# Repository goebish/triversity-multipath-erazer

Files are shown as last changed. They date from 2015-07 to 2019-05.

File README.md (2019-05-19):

# DIY Triversity 5.8 Ghz Video Receiver







## Building

Requires Arduino >= 1.6

PDQ_GFX for ST7735 must be installed in the Arduino libraries folder.

## Usage

### Main dialog

Press left or right to change channel, long press enable auto scan

Press up to enter calibration / bargraph dialog

### Calibration procedure

Allow the Triversity receiver to warm up for at least 5-10 minutes before calibrating.

- Start with transmitter switched off
- Press left / right to manually set frequency to the same as your transmitter
- Press up to enter calibration / bargraph dialog
- Set gain potentiometers to their maximum position
- Adjust zero adjust potentiometers until every channel read the same value in the 50-60 range, lower is better, but they must read the same value, ie 51 51 51
- Switch transmitter on
- Adjust gain potentiometer until every channel read 1000
- Press up to exit calibration dialog

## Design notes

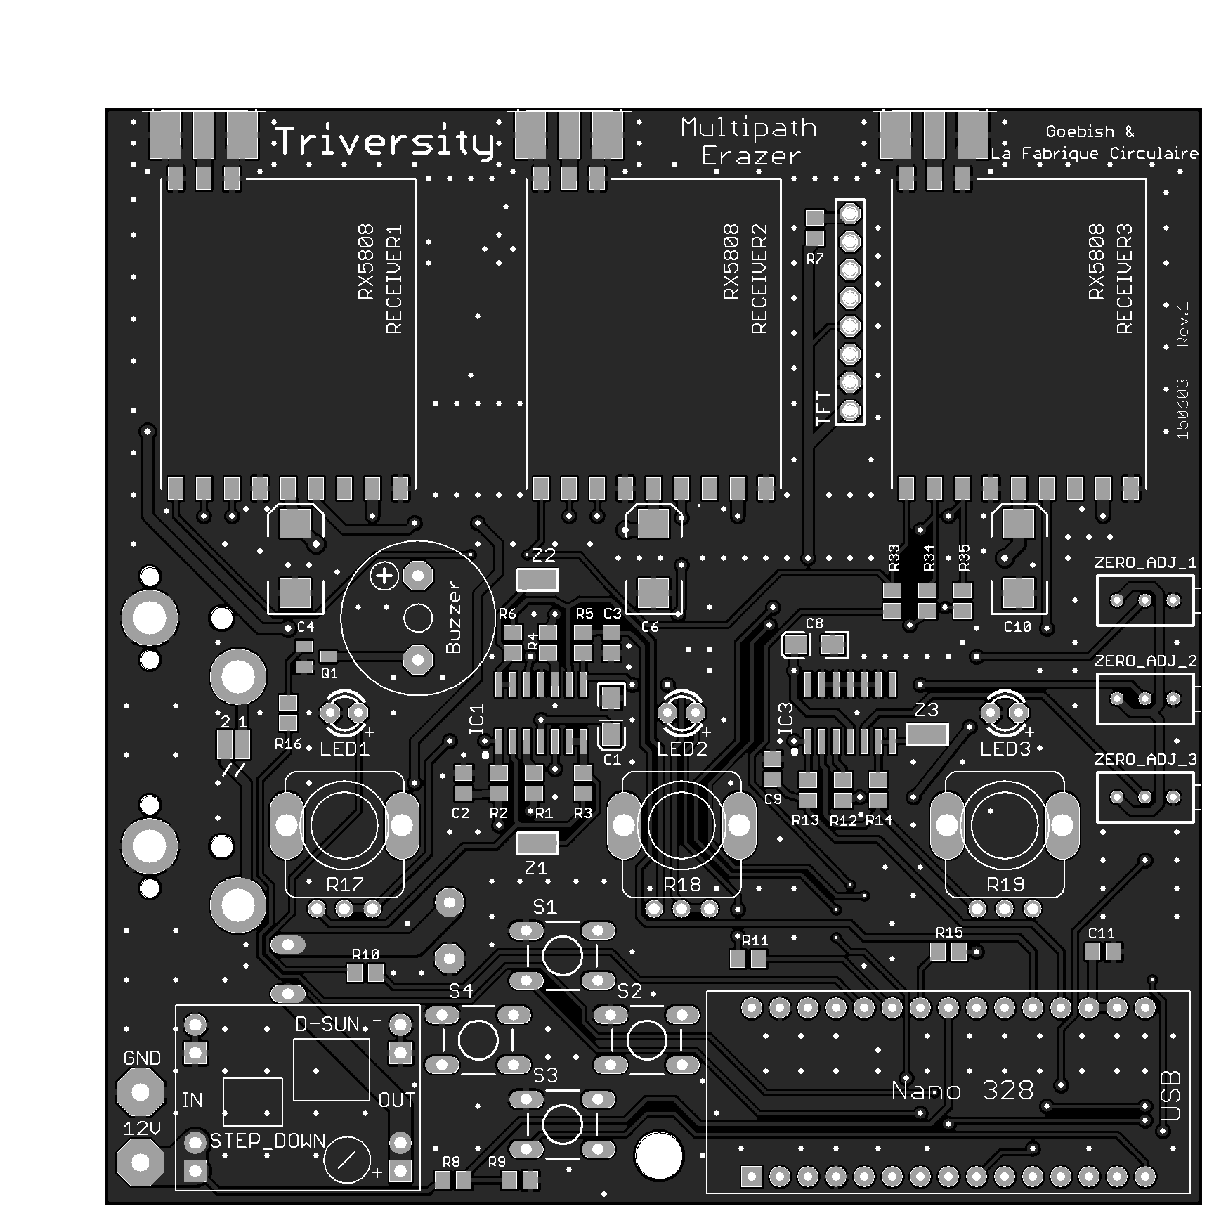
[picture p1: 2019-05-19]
Hardware/triversity_rev1_top.png

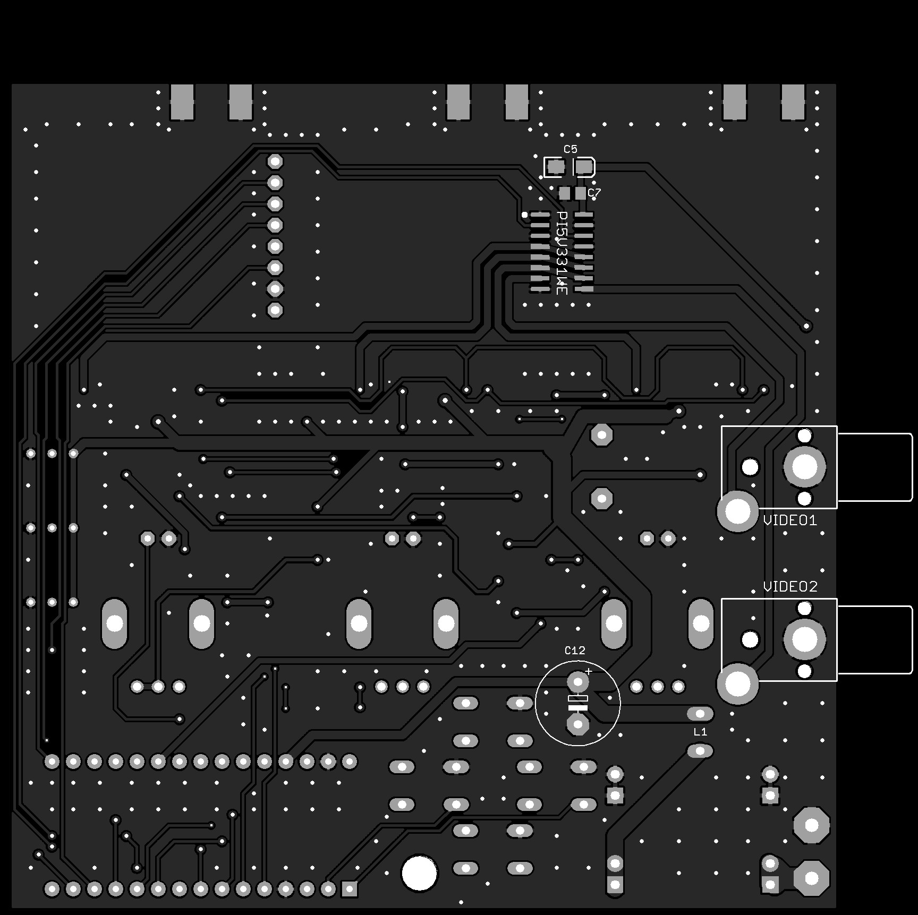
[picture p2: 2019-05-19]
Hardware/triversity_rev1_bottom.png

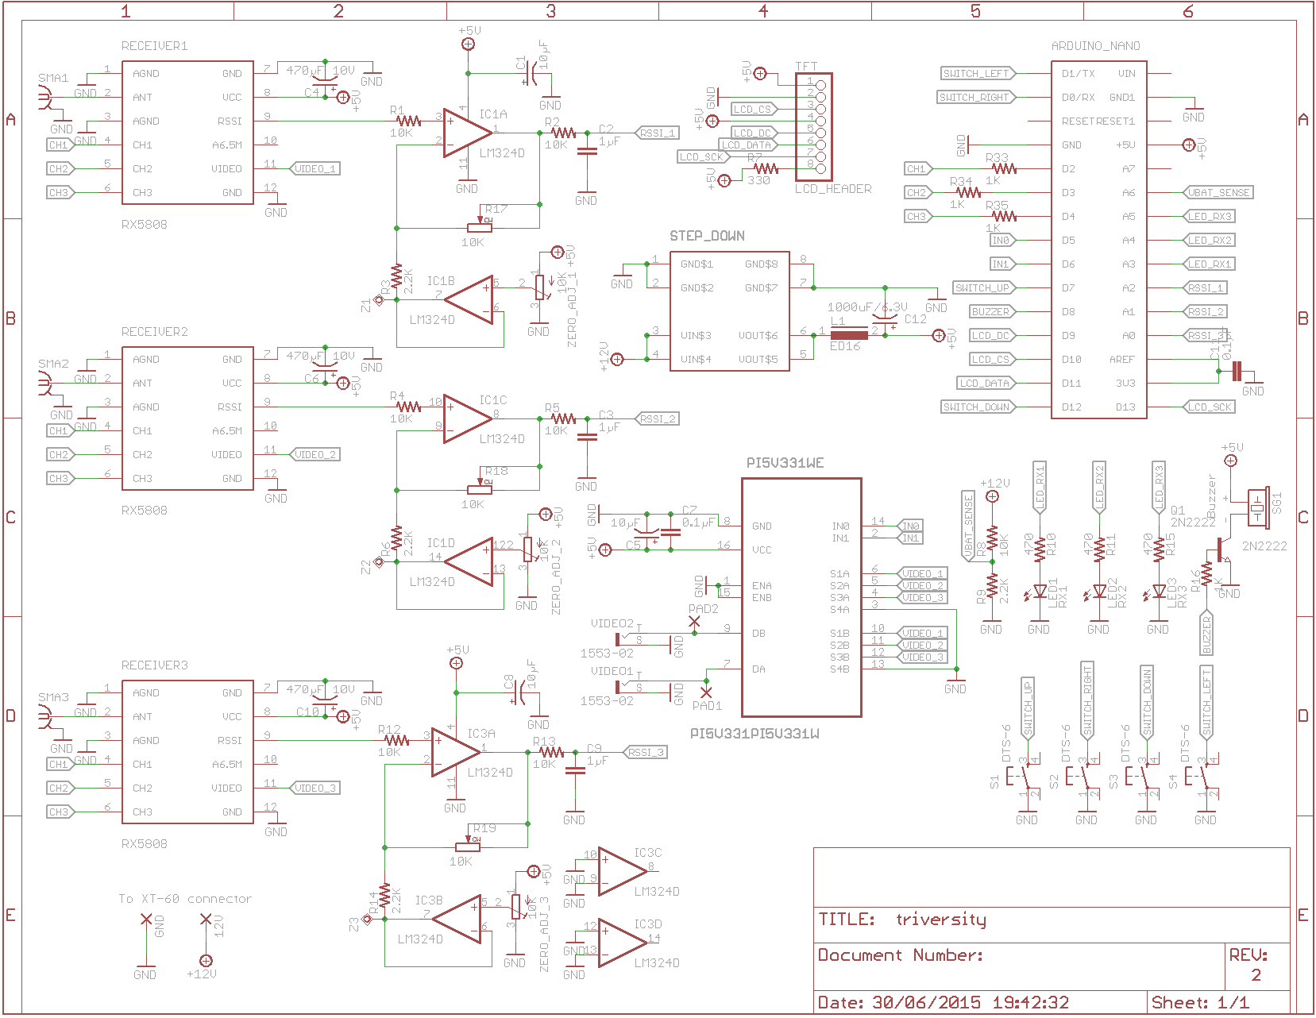
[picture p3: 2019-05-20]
Hardware/triversity_rev1.schematics.png

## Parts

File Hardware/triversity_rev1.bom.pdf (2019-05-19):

Parts | Qty | Value | Device
C7, C11 | 2 | 0.1µF | 0805 ceramic (2.0 mm × 1.25 mm)
C2, C3, C9 | 3 | 1µF | 0805 ceramic (2.0 mm × 1.25 mm)
R16, R33, R34, R35 | 4 | 1KΩ | 0805 (2.0 mm × 1.25 mm)
R3, R6, R9, R14 | 4 | 2.2K | 0805 (2.0 mm × 1.25 mm)
Q1 | 1 | 2N2222 | SOT23
C1, C5, C8 | 3 | 10µF | 1206 tantalum or ceramic (3.2 mm × 1.6 mm)
R17, R18, R19 | 3 | 10KΩ linear | Single RK09L
ZERO_ADJ_1, ZERO_ADJ_2, ZERO_ADJ_33 | 10KΩ | 3296X
R1, R2, R4, R5, R8, R12, R13 | 7 | 10KΩ | 0805 (2.0 mm × 1.25 mm)
R7 | 1 | 330Ω | 0805 (2.0 mm × 1.25 mm)
C4, C6, C10 | 3 | 470µF 10V | 7343 tantalum (7.3 mm × 4.3 mm)
R10, R11, R15 | 3 | 470Ω | 0805 (2.0 mm × 1.25 mm)
C12 | 1 | 1000uF 6.3V | PTH CPOL-USE5-10.5
VIDEO1, VIDEO2 | 2 | 1553-02 | RCA 1553-02
ARDUINO_NANO | 1 | ARDUINO NANO | Arduino Nano or clone
SG1 | 1 | Buzzer | F/CM12P
S1, S2, S3, S4 | 4 | DTS-6 | switch DTS-6 13mm
L1 | 1 | à déterminer … | ED16
TFT | 1 | ST7735 1.8" | 1.8" TFT LCD Display 128x160 Module ST7735S
IC1, IC3 | 2 | LM324D | SOIC-14
STEP_DOWN | 1 | BG SKU 951165 | Mini DC-DC Adjustable Power Supply Module
PI5V331WE | 1 | PI5V331WE | SOIC-16
LED1, LED2, LED3 | 3 | Ultra bright Red LED | PTH LED 3MM
RECEIVER1, RECEIVER2, RECEIVER3 | 3 | RX5808 | RX5808 SPI
SMA1, SMA2, SMA3 | 3 | SMA-142-0711-821/826 | SMA-142-0711-821/826

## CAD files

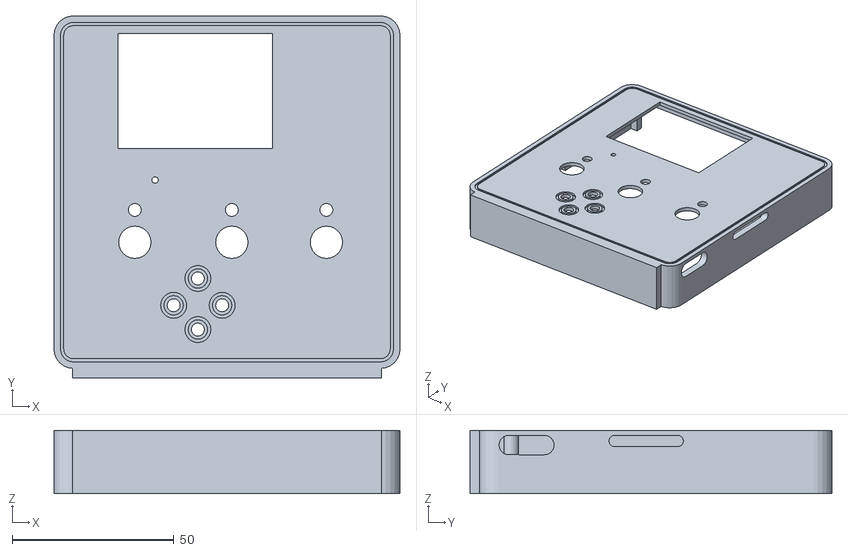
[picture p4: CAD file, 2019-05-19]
Hardware/casing/triversity_panel_front.stl
107.0 x 112.0 x 19.5

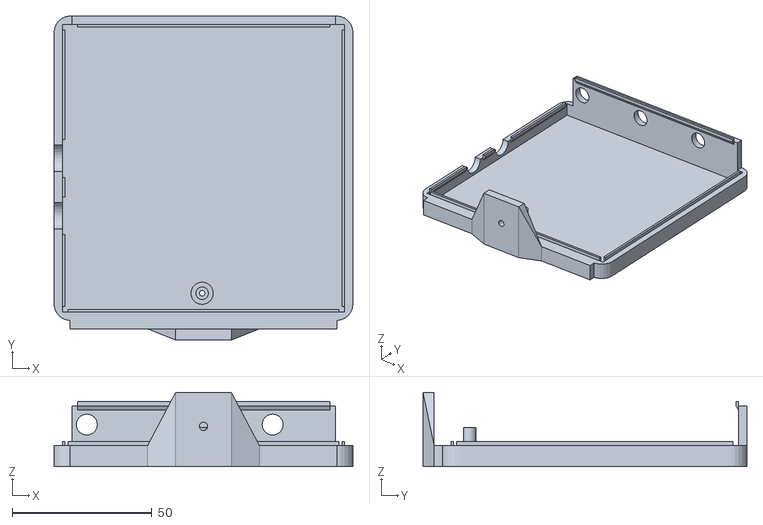
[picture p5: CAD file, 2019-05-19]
Hardware/casing/triversity_panel_back.stl
107.0 x 116.0 x 26.5

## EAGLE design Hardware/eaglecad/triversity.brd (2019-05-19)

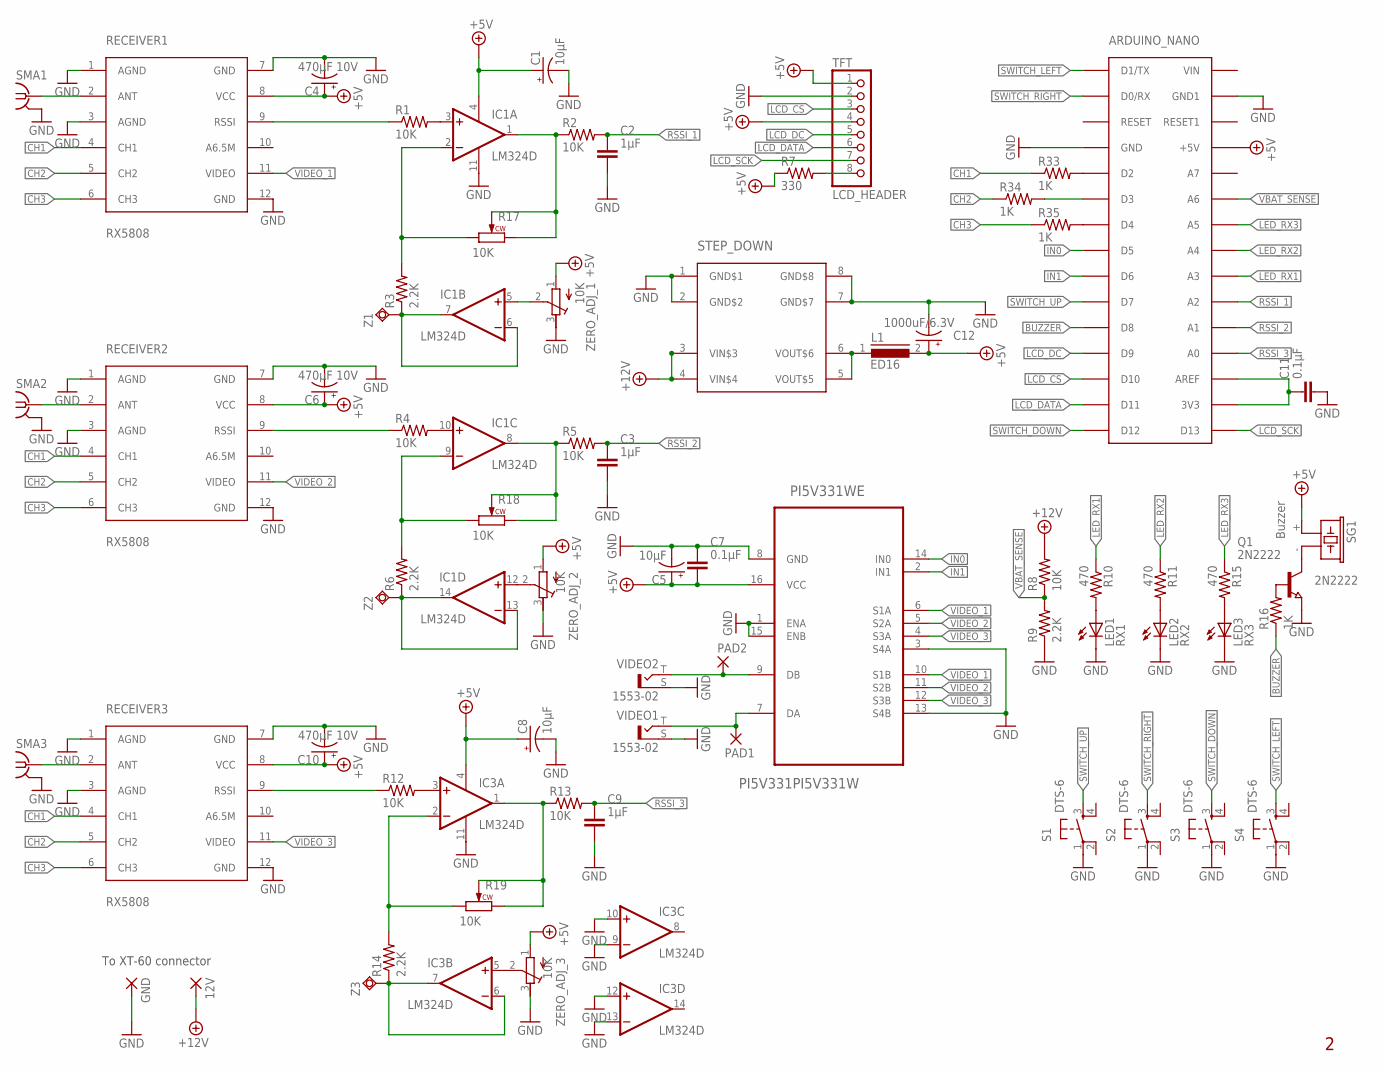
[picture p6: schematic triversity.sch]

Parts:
12V: WIREPAD4,16O1,6; 4,16O1,6
ARDUINO_NANO: ARDUINO_NANO; PDIP-32
C1, C5, C8: 10µF; EIA3216-KIT
C2, C3, C9: 1µF; C805
C4, C6, C10: 470µF 10V; EIA7343
C7, C11: 0.1µF; C805
C12: 1000uF/6.3V; E5-10,5
GND: WIREPAD4,16O1,6; 4,16O1,6
IC1, IC3: LM324D; SO14
L1: ED16
LED1: RX1; LED3MM
LED2: RX2; LED3MM
LED3: RX3; LED3MM
PAD1, PAD2: WIREPADSMD1,27-254; SMD1,27-2,54
PI5V331WE: PI5V331PI5V331W; SO16
Q1: 2N2222; SOT23
R1, R2, R4, R5, R8, R12, R13: 10K; M0805
R3, R6, R9, R14: 2.2K; M0805
R7: 330; M0805
R10, R11, R15: 470; M0805
R16, R33, R34, R35: 1K; M0805
R17, R18, R19: 10K; RK09L-SINGLE
RECEIVER1, RECEIVER2, RECEIVER3: RX5808
S1, S2, S3, S4: DTS-6
SG1: Buzzer; F/CM12P
SMA1, SMA2, SMA3: SMA-142-0711-821/826; J502-ND-142-0711-821/826
STEP_DOWN: LM2596_MODULE; LM2596-MODULE
TFT: LCD_HEADER; 1X08-CLEANBIG
VIDEO1, VIDEO2: 1553-02
Z1, Z2, Z3: TP-M; KEY-MINIATURE
ZERO_ADJ_1, ZERO_ADJ_2, ZERO_ADJ_3: 10K; RTRIM3296X

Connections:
3V3_AREF: ARDUINO_NANO.3V3, ARDUINO_NANO.AREF, C11.1
+5V: ARDUINO_NANO.+5V, C1.A (+), C4.A (+), C5.A (+), C6.A (+), C7.2, C8.A (+), C10.A (+), C12.+, IC1.4 (V+), IC3.4 (V+), L1.2, PI5V331WE.16 (VCC), R7.1, RECEIVER1.8 (VCC), RECEIVER2.8 (VCC), RECEIVER3.8 (VCC), SG1.+ (1), TFT.1, TFT.4, ZERO_ADJ_1.1 (E), ZERO_ADJ_2.1 (E), ZERO_ADJ_3.1 (E)
+12V: 12V.1, R8.2, STEP_DOWN.3 (VIN$3), STEP_DOWN.4 (VIN$4)
ANT1: RECEIVER1.2 (ANT), SMA1.1
ANT2: RECEIVER2.2 (ANT), SMA2.1
ANT3: RECEIVER3.2 (ANT), SMA3.1
BUZZER: ARDUINO_NANO.D8, R16.1
CH1: R33.1, RECEIVER1.4 (CH1), RECEIVER2.4 (CH1), RECEIVER3.4 (CH1)
CH2: R34.1, RECEIVER1.5 (CH2), RECEIVER2.5 (CH2), RECEIVER3.5 (CH2)
CH3: R35.1, RECEIVER1.6 (CH3), RECEIVER2.6 (CH3), RECEIVER3.6 (CH3)
GND: ARDUINO_NANO.GND, ARDUINO_NANO.GND1, C1.C (-), C2.2, C3.2, C4.C (-), C5.C (-), C6.C (-), C7.1, C8.C (-), C9.2, C10.C (-), C11.2, C12.-, GND.1, IC1.11 (V-), IC3.9 (-IN), IC3.10 (+IN), IC3.11 (V-), IC3.12 (+IN), IC3.13 (-IN), LED1.K (C), LED2.K (C), LED3.K (C), PI5V331WE.1 (ENA), PI5V331WE.3 (S4A), PI5V331WE.8 (GND), PI5V331WE.13 (S4B), PI5V331WE.15 (ENB), Q1.2 (E), R9.1, RECEIVER1.1 (AGND), RECEIVER1.3 (AGND), RECEIVER1.7 (GND), RECEIVER1.12 (GND), RECEIVER2.1 (AGND), RECEIVER2.3 (AGND), RECEIVER2.7 (GND), RECEIVER2.12 (GND), RECEIVER3.1 (AGND), RECEIVER3.3 (AGND), RECEIVER3.7 (GND), RECEIVER3.12 (GND), S1.1, S2.1, S3.1, S4.1, SMA1.G@1 (GND), SMA1.G@2 (GND), SMA1.G@3 (GND), SMA1.G@4 (GND), SMA2.G@1 (GND), SMA2.G@2 (GND), SMA2.G@3 (GND), SMA2.G@4 (GND), SMA3.G@1 (GND), SMA3.G@2 (GND), SMA3.G@3 (GND), SMA3.G@4 (GND), STEP_DOWN.1 (GND$1), STEP_DOWN.2 (GND$2), STEP_DOWN.7 (GND$7), STEP_DOWN.8 (GND$8), TFT.2, VIDEO1.S, VIDEO2.S, ZERO_ADJ_1.3 (A), ZERO_ADJ_2.3 (A), ZERO_ADJ_3.3 (A)
IN0: ARDUINO_NANO.D5, PI5V331WE.14 (IN0)
IN1: ARDUINO_NANO.D6, PI5V331WE.2 (IN1)
LCD_CS: ARDUINO_NANO.D10, TFT.3
LCD_DATA: ARDUINO_NANO.D11, TFT.6
LCD_DC: ARDUINO_NANO.D9, TFT.5
LCD_SCK: ARDUINO_NANO.D13, TFT.7
LED_RX1: ARDUINO_NANO.A3, R10.1
LED_RX2: ARDUINO_NANO.A4, R11.1
LED_RX3: ARDUINO_NANO.A5, R15.1
unnamed: IC1.3 (+IN), R1.2
unnamed: IC3.3 (+IN), R12.2
unnamed: IC1.1 (OUT), R2.1, R17.2 (W), R17.3 (CW)
unnamed: R7.2, TFT.8
unnamed: IC1.6 (-IN), IC1.7 (OUT), R3.1, Z1.P$1
unnamed: IC1.2 (-IN), R3.2, R17.1 (CCW)
unnamed: IC1.10 (+IN), R4.2
unnamed: IC1.5 (+IN), ZERO_ADJ_1.2 (S)
unnamed: IC1.8 (OUT), R5.1, R18.2 (W), R18.3 (CW)
unnamed: IC1.13 (-IN), IC1.14 (OUT), R6.1, Z2.P$1
unnamed: IC1.9 (-IN), R6.2, R18.1 (CCW)
unnamed: IC1.12 (+IN), ZERO_ADJ_2.2 (S)
unnamed: Q1.3 (C), SG1.- (2)
unnamed: IC3.1 (OUT), R13.1, R19.2 (W), R19.3 (CW)
unnamed: IC3.6 (-IN), IC3.7 (OUT), R14.1, Z3.P$1
unnamed: IC3.2 (-IN), R14.2, R19.1 (CCW)
unnamed: IC3.5 (+IN), ZERO_ADJ_3.2 (S)
unnamed: LED1.A, R10.2
unnamed: Q1.1 (B), R16.2
unnamed: L1.1, STEP_DOWN.5 (VOUT$5), STEP_DOWN.6 (VOUT$6)
unnamed: LED2.A, R11.2
unnamed: LED3.A, R15.2
unnamed: ARDUINO_NANO.D2, R33.2
unnamed: ARDUINO_NANO.D3, R34.2
unnamed: ARDUINO_NANO.D4, R35.2
RAW_RSSI1: R1.1, RECEIVER1.9 (RSSI)
RAW_RSSI2: R4.1, RECEIVER2.9 (RSSI)
RAW_RSSI3: R12.1, RECEIVER3.9 (RSSI)
RSSI_1: ARDUINO_NANO.A2, C2.1, R2.2
RSSI_2: ARDUINO_NANO.A1, C3.1, R5.2
RSSI_3: ARDUINO_NANO.A0, C9.1, R13.2
SWITCH_DOWN: ARDUINO_NANO.D12, S3.3
SWITCH_LEFT: ARDUINO_NANO.D1/TX, S4.3
SWITCH_RIGHT: ARDUINO_NANO.D0/RX, S2.3
SWITCH_UP: ARDUINO_NANO.D7, S1.3
VBAT_SENSE: ARDUINO_NANO.A6, R8.1, R9.2
VIDEO_1: PI5V331WE.6 (S1A), PI5V331WE.10 (S1B), RECEIVER1.11 (VIDEO)
VIDEO_2: PI5V331WE.5 (S2A), PI5V331WE.11 (S2B), RECEIVER2.11 (VIDEO)
VIDEO_3: PI5V331WE.4 (S3A), PI5V331WE.12 (S3B), RECEIVER3.11 (VIDEO)
VIDEO_OUT1: PAD1.1, PI5V331WE.7 (DA), VIDEO1.T
VIDEO_OUT2: PAD2.1, PI5V331WE.9 (DB), VIDEO2.T

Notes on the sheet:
To XT-60 connector
2N2222

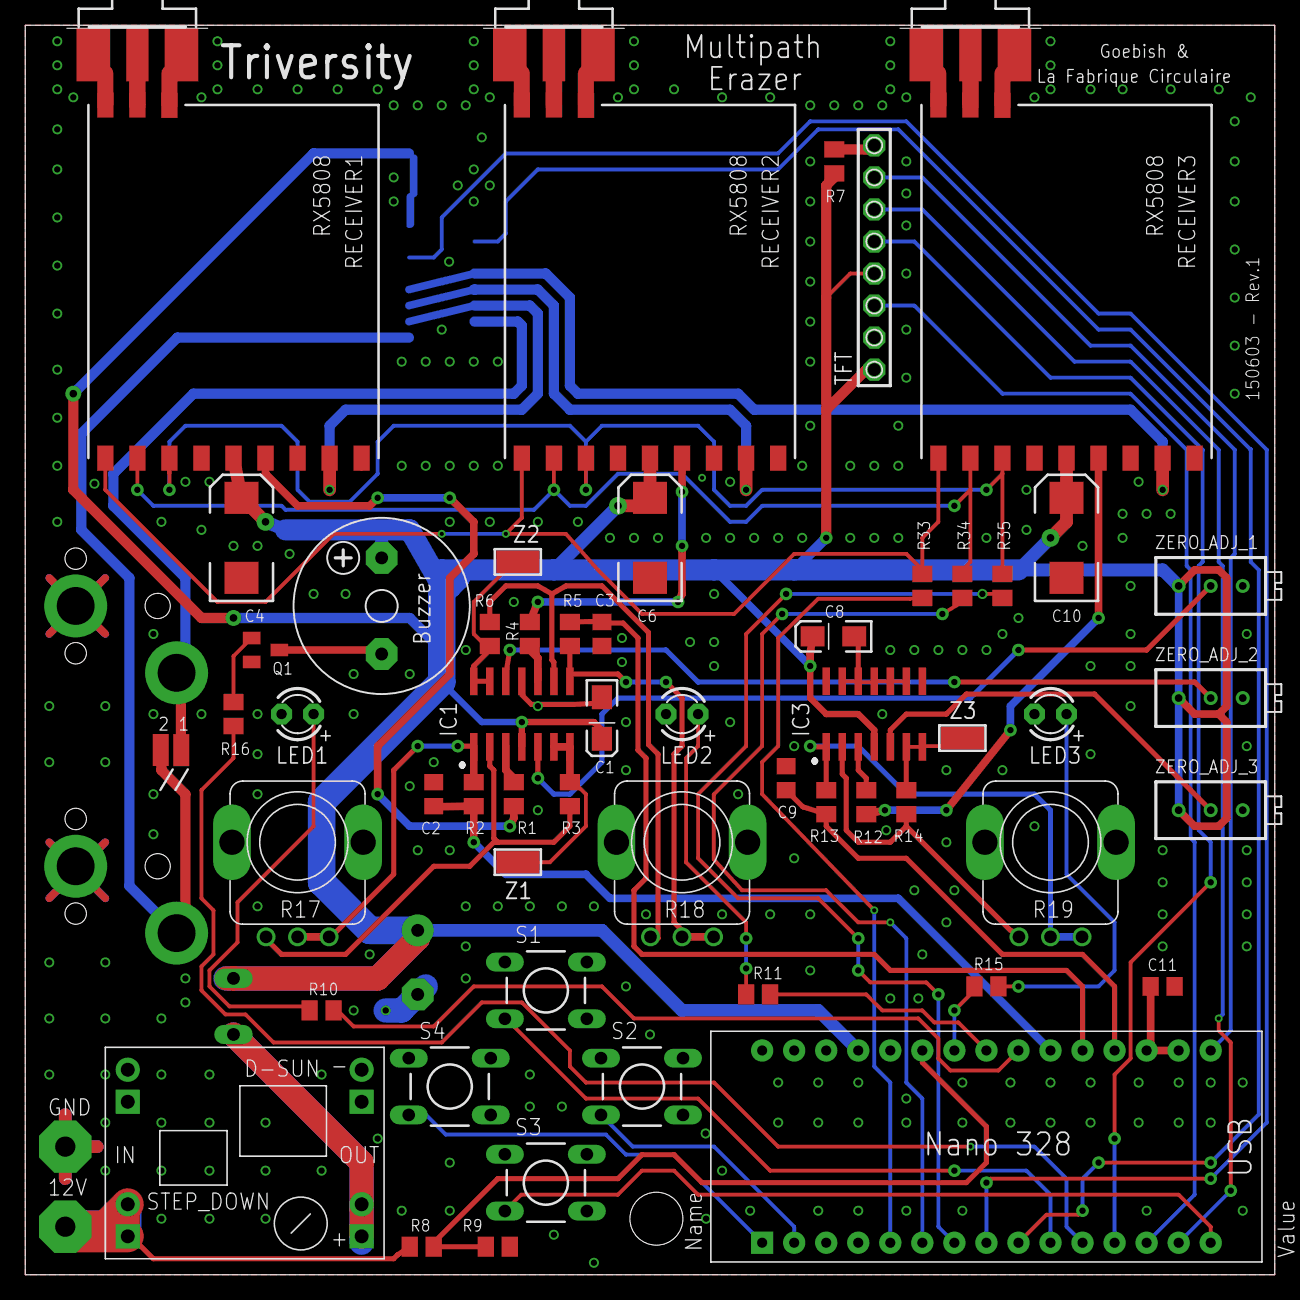
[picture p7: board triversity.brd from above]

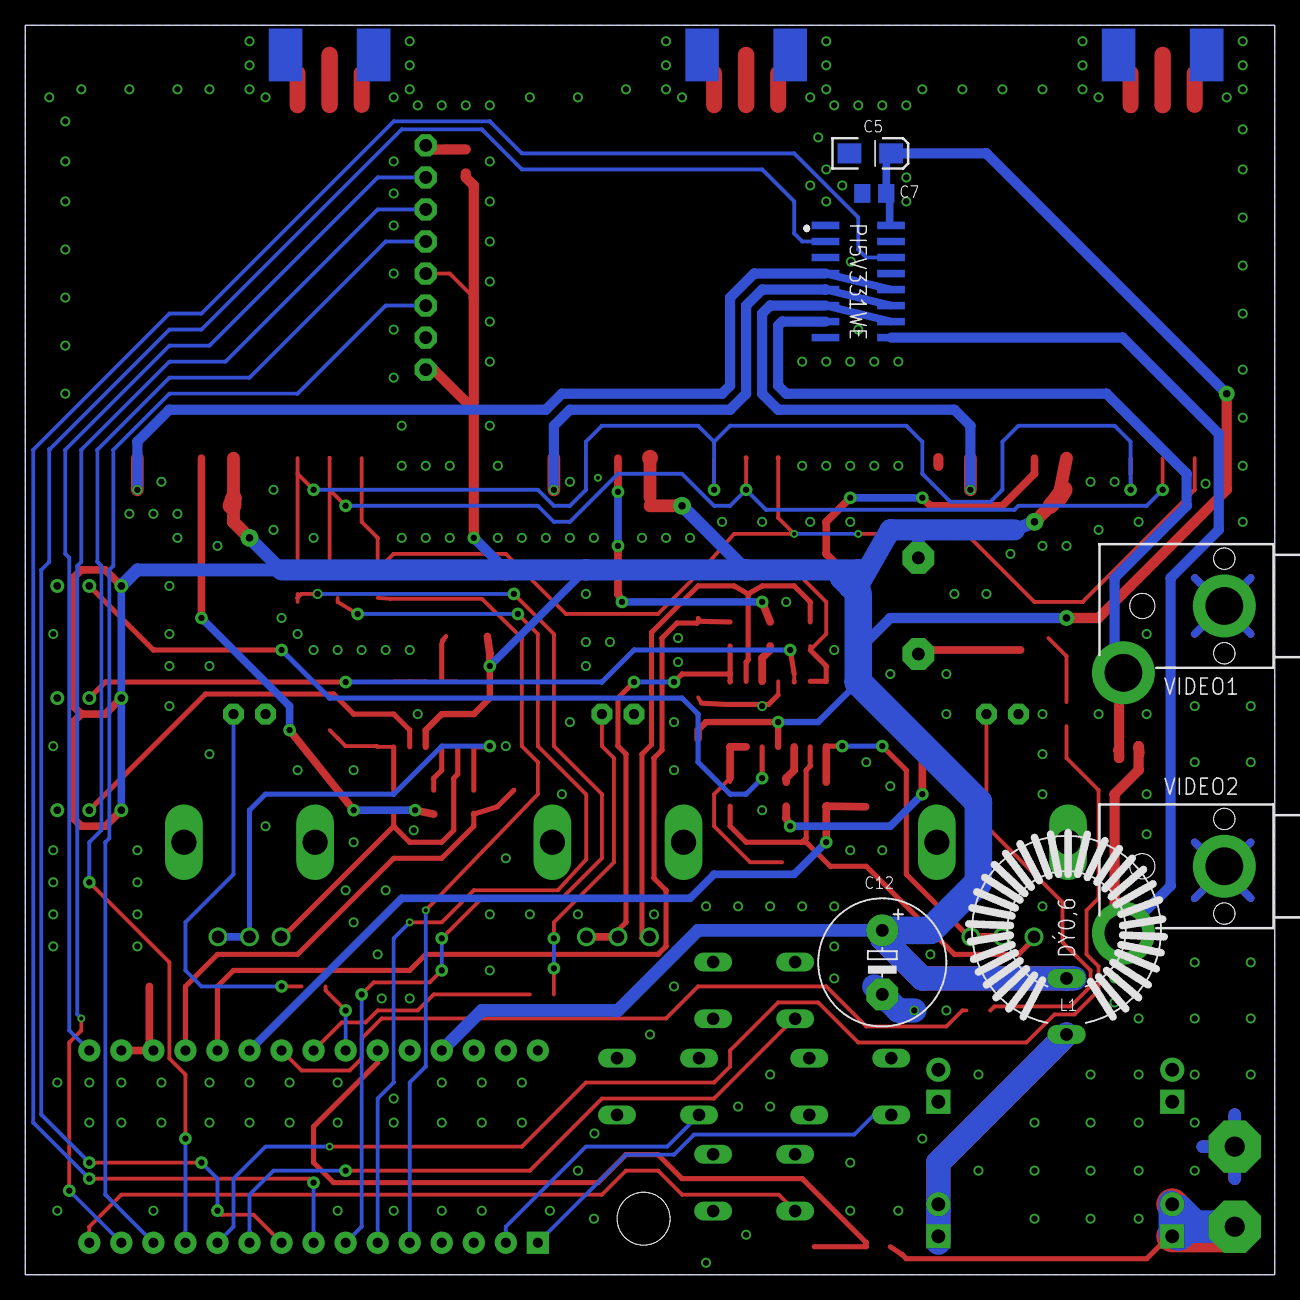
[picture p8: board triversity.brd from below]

Board: 2 copper layers, 99.1 x 99.1 mm, 69 parts (7 on the bottom side), 61 nets.

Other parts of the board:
U$1: ST7735-SPI

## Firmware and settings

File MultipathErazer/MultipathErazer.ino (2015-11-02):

#include "config.h"
#include "utils.h"
#include "pinout.h"
#include "display.h"
#include <PDQ_GFX.h>
#include "PDQ_ST7735_config.h"
#include <PDQ_ST7735.h>
PDQ_ST7735 tft;

#define NUMBER_OF_RECEIVER 3
#define VBAT_FACTOR 190
#define RSSI_STABILIZATION_TIME 50

const unsigned char RSSI_Pin[3] = { A2, A1, A0}; //Analog Pin

// Channels with their Mhz Values
const uint16_t channelFreqTable[] PROGMEM = {
    // Channel 1 - 8
    5865, 5845, 5825, 5805, 5785, 5765, 5745, 5725, // Band A  00 - 07
    5733, 5752, 5771, 5790, 5809, 5828, 5847, 5866, // Band B  08 - 15
    5705, 5685, 5665, 5645, 5885, 5905, 5925, 5945, // Band E  16 - 23
    5740, 5760, 5780, 5800, 5820, 5840, 5860, 5880, // IRC/FS  24 - 31
    5658, 5695, 5732, 5769, 5806, 5843, 5880, 5917  // Race    32 - 39
};

// All Channels of the above list ordered by Mhz
const uint8_t channelList[] PROGMEM = {
    19, 32, 18, 17, 33, 16,  7, 34,  8, 24,
     6,  9, 25,  5, 35, 10, 26,  4, 11, 27,
     3, 36, 12, 28,  2, 13, 29, 37,  1, 14,
    30,  0, 15, 31, 38, 20, 21, 39, 22, 23
};

const uint8_t beep_length[4] = {0, 1, 4, 10};

uint16_t RSSI_Value[NUMBER_OF_RECEIVER];
uint8_t vbat;
uint8_t MaxSource = 0;
int16_t max_rssi = 0;
int8_t max_rssi_scan_index;
bool show_active_leds = true;
uint8_t current_menu_item;
boolean scan_first_pass = true;
uint16_t scan_max_found = 0;
uint16_t scan_last_max_found = 0;
uint8_t scan_channel;
uint8_t channelIndex;
uint8_t scan_best_index=0;
uint16_t anim_count;
uint32_t last_switch_beep=0;
bool searching=false;

// timers
uint32_t saveSettings = 0;
uint32_t checkVbat = 0;

enum e_STATES{
    STATE_MAIN,      // channel selection
    STATE_MAIN_MENU, // main menu
    STATE_CALIB,     // bar graph
    STATE_SCANNER,   // band scanner
    STATE_SETTINGS_MENU,  // settings menu
};

static uint8_t state = STATE_MAIN;

void setup()
{
    // read settings from eeprom
    readConfig();
    // init vRXs
    SPI_vRX_init();
    // init display
    TFT_init_display();
    // set analog reference
    analogReference(EXTERNAL);
    // setup leds
    DDRC |= 0b00111000; // output
    // setup pi5v331
    initSwitcher();
    // setup switches
    DDRD &= ~0b10000011; // input
    DDRB &= ~0b00010000;
    PORTD|=  0b10000011; // pull up
    PORTB|=  0b00010000;
    // setup buzzer
    DDRB |= 0b00000001; // output
    BUZZ_OFF;
    // setup 250khz adc (slightly more than recommended 200 khz max setting
    //setAdcPrescaler(ADC_PS_64);

    // splash screen
    displaySplash();

    // start with main dialog
    initState();
}

void loop()
{
    switch(state) {
        case STATE_MAIN:
            processMainState();
            break;
        case STATE_CALIB:
            processCalibState();
            break;
        case STATE_MAIN_MENU:
            processMainMenu();
            break;
        case STATE_SCANNER:
            processScanner();
            break;
        case STATE_SETTINGS_MENU:
            processSettingsMenu();
            break;
    }

    // save settings to eeprom
    if(saveSettings && millis() > saveSettings)
    {
        writeConfig();
        saveSettings = 0;
    }

    // refresh vbat
    if(millis() > checkVbat) {
        checkVbat = millis() + 20000; // check every 20s
        vbat = map( analogRead(VBAT)*10, 0, 10240, 0, VBAT_FACTOR);
        updateMainDialog(_BV(MAIN_BATTERY));
    }

    alarmBeep();
    switchBestRSSI();
}

void initState()
{
    switch(state) {
        case STATE_MAIN:
            updateMainDialog(_BV(MAIN_INIT) | _BV(MAIN_BAND) | _BV(MAIN_CHANNEL));
            SPI_vRX_set_frequency(pgm_read_word_near(channelFreqTable + config.current_channel));
            show_active_leds=true;
            break;
        case STATE_CALIB:
            updateCalibDialog(_BV(CALIB_INIT) | _BV(CALIB_HEADER));
            show_active_leds=true;
            break;
        case STATE_MAIN_MENU:
            current_menu_item = MAIN_MENU_EXIT;
            updateMainMenuDialog(_BV(MAIN_MENU_INIT) | _BV(MAIN_MENU_ITEMS));
            show_active_leds=true;
            break;
        case STATE_SCANNER:
            scan_first_pass = true;
            scan_max_found = 0;
            scan_last_max_found = 0;
            searching = true;
            updateScannerDialog(_BV(SCANNER_INIT));
            show_active_leds=false;
            scan_channel = 0;
            channelIndex = pgm_read_byte_near(channelList + scan_channel);
            SPI_vRX_set_frequency(pgm_read_word_near(channelFreqTable + channelIndex));
            delay(100);
            break;
        case STATE_SETTINGS_MENU:
            current_menu_item = SETTINGS_MENU_EXIT;
            updateSettingsMenuDialog(_BV(SETTINGS_MENU_INIT) | _BV(SETTINGS_MENU_ITEMS));
            show_active_leds=true;
            break;
    }
}

void processSettingsMenu()
{
    uint8_t i;
    if(BTN_UP || BTN_DOWN) {
        if(BTN_UP && current_menu_item > 0) {
            shortbeep();
            current_menu_item --;
            updateSettingsMenuDialog(_BV(SETTINGS_MENU_ITEMS));
        } else
        if(BTN_DOWN && current_menu_item < SETTINGS_MENU_NB_ITEMS-1) {
            shortbeep();
            current_menu_item ++;
            updateSettingsMenuDialog(_BV(SETTINGS_MENU_ITEMS));
        }
        waitButtonsRelease();
    } else
    if(BTN_LEFT || BTN_RIGHT) {
        shortbeep();
        uint8_t auto_repeat = 4;
        switch(current_menu_item) {
            case SETTINGS_MENU_EXIT:
                state = STATE_MAIN_MENU;
                initState();
                saveSettings = millis();
                waitButtonsRelease();
                break;
            case SETTINGS_MENU_VBAT_ALARM:
                if(BTN_LEFT && config.vbat_alarm > VBAT_ALARM_MIN)
                        config.vbat_alarm --;
                else if(BTN_RIGHT && config.vbat_alarm < VBAT_ALARM_MAX)
                        config.vbat_alarm ++;
                vbat = map( analogRead(VBAT)*10, 0, 10240, 0, VBAT_FACTOR);
                updateMainDialog(_BV(MAIN_BATTERY) | _BV(MAIN_FORCE_BATTERY_REDRAW));
                updateSettingsMenuDialog(_BV(SETTINGS_MENU_CHANGE_SETTING));
                while(BTN_ANY && auto_repeat--)
                    delay(50);
                break;
            case SETTINGS_MENU_BEEP_VOLUME:
                if(BTN_LEFT && config.beep_volume > BEEP_OFF)
                    config.beep_volume--;
                else if(BTN_RIGHT && config.beep_volume < BEEP_LOUDER)
                    config.beep_volume++;
                updateSettingsMenuDialog(_BV(SETTINGS_MENU_CHANGE_SETTING));
                waitButtonsRelease();
                break;
            case SETTINGS_MENU_PERIOD:
                if(BTN_LEFT && config.switch_period > 0)
                    if(config.switch_period <= 50)
                        config.switch_period--;
                    else
                        config.switch_period -= 10;
                else if(BTN_RIGHT && config.switch_period < MAX_PERIOD)
                    if(config.switch_period < 50)
                        config.switch_period++;
                    else
                        config.switch_period += 10;
                updateSettingsMenuDialog(_BV(SETTINGS_MENU_CHANGE_SETTING));
                while(BTN_ANY && auto_repeat--)
                    delay(15);
                break;
            case SETTINGS_MENU_FACTORY_RESET:
                for(i=0; i<3; i++) {
                    BUZZ_ON;
                    delay(100);
                    BUZZ_OFF;
                    delay(100);
                }
                state = STATE_MAIN;
                resetConfig();
                initState();
                waitButtonsRelease();
                break;
        }
    }
}

void processScanner()
{
    if(BTN_ANY) {
        if(scan_first_pass) {
            searching = false;
            shortbeep();
            state = STATE_MAIN;
            initState();
            waitButtonsRelease();
            return;
        }
        if(searching) {
            shortbeep();
            show_active_leds = true;
            searching = false;
            updateScannerDialog(_BV(SCANNER_CHOICE));
            SPI_vRX_set_frequency(pgm_read_word_near(channelFreqTable + scan_best_index));
            waitButtonsRelease();
            return;
        }
        if(BTN_LEFT) { // No
            shortbeep();
            state = STATE_MAIN;
            initState();
            waitButtonsRelease();
            return;
        } else
        if(BTN_RIGHT) { // Yes
            shortbeep();
            config.current_channel = scan_best_index;
            saveSettings = millis();
            state = STATE_MAIN;
            initState();
            waitButtonsRelease();
            return;
        }
    }
    if(searching) {
        channelIndex = pgm_read_byte_near(channelList + scan_channel);
        PORTC = (PORTC & ~0b111000) | (0b1000 << ((anim_count++/2) % NUMBER_OF_RECEIVER));
        SPI_vRX_set_frequency(pgm_read_word_near(channelFreqTable + channelIndex));
        updateScannerDialog(_BV(SCANNER_MARKER));
        wait(RSSI_STABILIZATION_TIME);
        switchBestRSSI();
        updateScannerDialog(_BV(SCANNER_GRAPH));
        if(max_rssi > scan_max_found) {
            scan_max_found = max_rssi;
            max_rssi_scan_index = scan_channel;
            if(scan_max_found > scan_last_max_found && !scan_first_pass) {
                updateScannerDialog(_BV(SCANNER_BEST));
                scan_best_index = pgm_read_byte_near(channelList + max_rssi_scan_index);
                scan_last_max_found = scan_max_found;
            }
        }
        scan_channel ++;
        if(scan_channel > 39) {
            scan_first_pass = false;
            updateScannerDialog(_BV(SCANNER_BEST));
            scan_best_index = pgm_read_byte_near(channelList + max_rssi_scan_index);
            scan_channel = 0;
            scan_last_max_found = scan_max_found;
            scan_max_found = 0;
        }
    }        
}

void processCalibState()
{
    static uint32_t refresh;
    if(BTN_RIGHT || BTN_LEFT) { // change current channel
        changeChannel();
    } else
    if(BTN_DOWN || BTN_UP) // return to main dialog
    {
        shortbeep();
        state = STATE_MAIN;
        initState();
        waitButtonsRelease();
        return;
    }
    if(millis() > refresh) {
        refresh = millis() + 1000/5; // x fps
        updateCalibDialog(_BV(CALIB_VALUES) | _BV(CALIB_BARS));
    }
}

void processMainMenu()
{
    if(BTN_UP || BTN_DOWN) {
        if(BTN_UP && current_menu_item > 0) {
            shortbeep();
            current_menu_item --;
            updateMainMenuDialog(_BV(MAIN_MENU_ITEMS));
        } else
        if(BTN_DOWN && current_menu_item < MAIN_MENU_NB_ITEMS-1) {
            shortbeep();
            current_menu_item ++;
            updateMainMenuDialog(_BV(MAIN_MENU_ITEMS));
        }
        waitButtonsRelease();
    } else
    if(BTN_LEFT || BTN_RIGHT) {
        shortbeep();
        switch(current_menu_item) {
            case MAIN_MENU_EXIT:
                state = STATE_MAIN;
                break;
            case MAIN_MENU_LEVELS:
                state = STATE_CALIB;
                break;
            case MAIN_MENU_SCANNER:
                state = STATE_SCANNER;
                break;
            case MAIN_MENU_SETTINGS:
                state = STATE_SETTINGS_MENU;
                break;
        }
        waitButtonsRelease();
        initState();
    }
}

// previous / next channel, long press = auto search
void changeChannel()
{
        shortbeep();
        if(BTN_RIGHT) {
            config.current_channel ++;
            if(config.current_channel > 39) {
                config.current_channel = 0;
            }
        }
        else if(BTN_LEFT) {
            config.current_channel --;
            if(config.current_channel < 0) {
                config.current_channel = 39;
            }
        }
        SPI_vRX_set_frequency(pgm_read_word_near(channelFreqTable + config.current_channel));
        switch(state) {
            case STATE_MAIN:
                updateMainDialog(_BV(MAIN_BAND) | _BV(MAIN_CHANNEL));
                break;
            case STATE_CALIB:
                updateCalibDialog(_BV(CALIB_HEADER));
                break;
        }
        uint8_t autoRepeat = 4;
        while(BTN_ANY && autoRepeat--) {
            delay(40);
            switchBestRSSI();
        }
        // long press = auto scan
        if(BTN_ANY && max_rssi < config.auto_threshold) {
            searching = true;
            tft.setTextColor(ST7735_WHITE, ST7735_BLACK);
            tft.setTextSize(1);
            switch(state) {
                case STATE_MAIN:
                    tft.setCursor(5,4);
                    break;
                case STATE_CALIB:
                    updateCalibDialog( _BV(CALIB_RESET_BARS) | _BV(CALIB_BARS));
                    tft.fillRect(36, 39, 84 , 16, ST7735_BLACK);
                    tft.drawRect(36, 39, 84 , 16, ST7735_WHITE);
                    tft.setCursor(40, 43);
                    break;
            }
            printText(&misc_string[STRING_SEARCHING]);
            int8_t direction=1;
            if(BTN_LEFT) {
                direction = -1;
            }
            bool button_released=false;
            show_active_leds=false;
            while(!BTN_ANY || !button_released) {
                config.current_channel += direction;
                if(config.current_channel > 39) {
                    config.current_channel = 0;
                }
                if(config.current_channel < 0) {
                    config.current_channel = 39;
                }
                SPI_vRX_set_frequency(pgm_read_word_near(channelFreqTable + config.current_channel));
                // LEDs animation
                anim_count += direction;
                PORTC = (PORTC & ~0b111000) | (0b1000 << ((anim_count/2) % NUMBER_OF_RECEIVER));
                switch(state) {
                    case STATE_MAIN:
                        updateMainDialog(_BV(MAIN_BAND) | _BV(MAIN_CHANNEL));
                        break;
                    case STATE_CALIB:
                        updateCalibDialog(_BV(CALIB_HEADER));
                        break;
                }
                // let rx stabilize on new frequency
                if((direction == 1 && config.current_channel % 8 == 0) ||
                   (direction ==-1 && config.current_channel % 8 == 7)) {
                    shortbeep(); // beep on band change
                    wait(RSSI_STABILIZATION_TIME-8);
                } else {
                    wait(RSSI_STABILIZATION_TIME);
                }
                switchBestRSSI();
                if(state == STATE_CALIB) {
                    updateCalibDialog(_BV(CALIB_BARS) | _BV(CALIB_VALUES));
                }
                // signal found ?
                if(max_rssi >= config.auto_threshold) {
                    // try to avoid false positive
                    wait(RSSI_STABILIZATION_TIME*3);
                    switchBestRSSI();
                    if(max_rssi >= config.auto_threshold) {
                        shortbeep();
                        delay(100);
                        shortbeep();
                        delay(100);
                        break;
                    }                        
                }
                if(!BTN_ANY) {
                    button_released = true;
                }
                alarmBeep();
            }
            if(state == STATE_MAIN) {
                refreshTitle();
            }
            else if(state == STATE_CALIB) {
                tft.fillRect(36, 39, 84 , 16, ST7735_BLACK);
                updateCalibDialog(_BV(CALIB_SCALES));
            }
            shortbeep();
        }
        searching = false;
        waitButtonsRelease();
        saveSettings = millis() + 3000; // save settings 3s after last change
        show_active_leds = true;
}

void processMainState()
{
    if(BTN_UP || BTN_DOWN) { // main menu
        shortbeep();
        state = STATE_MAIN_MENU; // STATE_CALIB;
        initState();
        waitButtonsRelease();
        return;
    } else
    if(BTN_RIGHT || BTN_LEFT) { // change current channel
        changeChannel();
    }
}

void switchBestRSSI()
{
    static uint32_t next_switch = 0;
    max_rssi = 0;
    for(uint8_t i = 0; i < NUMBER_OF_RECEIVER; i++) {
        RSSI_Value[i] = analogRead(RSSI_Pin[i]);
        if(RSSI_Value[i] > max_rssi) {
            max_rssi = RSSI_Value[i];
            MaxSource = i;
        }
    }
    if(millis() >= next_switch) {
        select(MaxSource);
        next_switch = millis() + config.switch_period;
    }
}

// short blocking beep for button press
void shortbeep()
{
    BUZZ_ON;
    delay(8);
    BUZZ_OFF;
}

// alarm beep management, must be called regularly
void alarmBeep()
{
    if(vbat <= config.vbat_alarm) {
        // every 5 seconds
        uint32_t now = millis() % 5000;
        // for 2 seconds
        if(now < 2000) {
            // beep 250ms every 500ms
            if(now%500 < 250) {
                BUZZ_ON;
            } else {
                BUZZ_OFF;
            }
        }
    }
    else if(searching==false && millis() < last_switch_beep + beep_length[config.beep_volume]) {
        BUZZ_ON;
    } else
        BUZZ_OFF;
}

// wait buttons release
void waitButtonsRelease()
{
    uint32_t timeout;
    while(BTN_ANY) {
        timeout = millis()+20;
        while(millis() < timeout)
            switchBestRSSI();
        alarmBeep();
    }
}

// wait or exit if button press
void wait(uint8_t msec)
{
    uint32_t timeout = millis() + msec;
    while(!BTN_ANY && millis() < timeout) {
        ;
    }
}

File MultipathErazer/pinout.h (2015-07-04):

// global pinout

// TFT LCD
#define TFT_CS (uint8_t)    10
#define TFT_RST (uint8_t)   A7   // connected to +3.3
#define TFT_DC (uint8_t)    9
#define TFT_SCLK (uint8_t)  13
#define TFT_DATA (uint8_t)  11

// buttons
#define BTN_UP_PIN  (uint8_t)   7
#define BTN_RIGHT_PIN (uint8_t) 0
#define BTN_DOWN_PIN (uint8_t)  12
#define BTN_LEFT_PIN (uint8_t)  1

#define BTN_UP      (!(PIND & 0b10000000))
#define BTN_RIGHT   (!(PIND & 0b00000001))
#define BTN_DOWN    (!(PINB & 0b00010000))
#define BTN_LEFT    (!(PIND & 0b00000010))
#define BTN_ANY     (BTN_UP|BTN_RIGHT|BTN_LEFT|BTN_DOWN)


// SPI vRX
#define VRX_DATA (uint8_t)  2 // PD2 - CH1 
#define VRX_EN (uint8_t)    3 // PD3 - CH2
#define VRX_CLK (uint8_t)   4 // PD4 - CH3

// RSSI vRX
#define RSSI_1 (uint8_t)    A2
#define RSSI_2 (uint8_t)    A1
#define RSSI_3 (uint8_t)    A0 

// LEDs
#define LED_VRX_1 (uint8_t) A3 
#define LED_VRX_2 (uint8_t) A4 
#define LED_VRX_3 (uint8_t) A5 

// analog multiplexer control
#define PI5V311_IN0 (uint8_t) 5 // PD5
#define PI5V311_IN1 (uint8_t) 6 // PD6

// misc
#define BUZZER (uint8_t)    8   // PB0
#define BUZZ_OFF PORTB &= ~0b00000001
#define BUZZ_ON  PORTB |=  0b00000001

#define VBAT (uint8_t)      A6

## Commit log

2015-07-04 Show led for active vRX + all other vRX(s) with same RSSI
2015-07-05 Fix beep when auto scan is canceled
    [MultipathErazer.ino]
2015-07-05 Draw larger rectangle around current channel #
2015-07-05 Fix start of auto scan when already on good channel
    [MultipathErazer.ino]
2015-07-05 Add led animation during auto scan
2015-07-05 Better LEDs animations
2015-07-05 Fix calibration bargraphs
2015-07-05 Fix RSSI values display in calibration dialog
    [display.ino]
2015-07-07 Fix main dialog title refreshed on each pass
    [MultipathErazer.ino]
2015-07-09 Add voltage alarm beep, fixed at 10.9 Volt for now
    [MultipathErazer.ino]
2015-07-13 Fix scanner bars height
    [display.ino]
2015-07-13 Avoid false positive during auto search
    [MultipathErazer.ino, display.ino]
2015-07-14 Fix beep when searching in backward direction
    [MultipathErazer.ino]
2015-07-14 Smoother battery voltage refresh
2015-11-02 Add settings menu, beep on switch, battery alarm setting, minimum switch period setting
2019-05-19 Add hardware
    [triversity.GBL, triversity.GBO, triversity.GBP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]
2019-05-19 Add pcb renderings
2019-05-19 Add casing
    [triversity_panel_back.stl, triversity_panel_front.stl]
2019-05-20 Add png schematics

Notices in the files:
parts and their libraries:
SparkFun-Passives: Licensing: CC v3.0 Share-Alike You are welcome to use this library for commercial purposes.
